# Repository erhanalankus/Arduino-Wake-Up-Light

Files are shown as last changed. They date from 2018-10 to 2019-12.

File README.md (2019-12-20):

# Arduino Wake Up Light

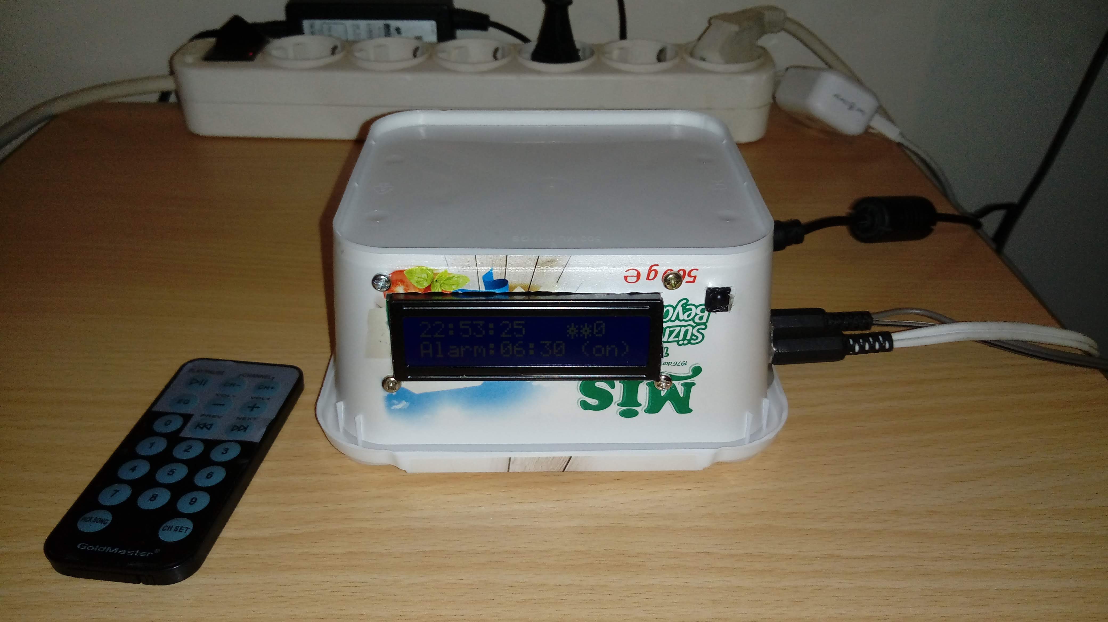
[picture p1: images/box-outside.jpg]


An alarm clock which turns on the lights very slowly. Lights can be controlled manually with an IR remote. White LED strip is for the alarm, Red LED strip is for soft light to use in the evening. It also has a buzzer, which is used to making gentle "tick" sounds when the light reaches full brightness(after 30 minutes). The tick frequency starts at one tick every two seconds, it doubles its speed after every ten minutes. The sound can be turned off.

# Step 1: Build the circuit

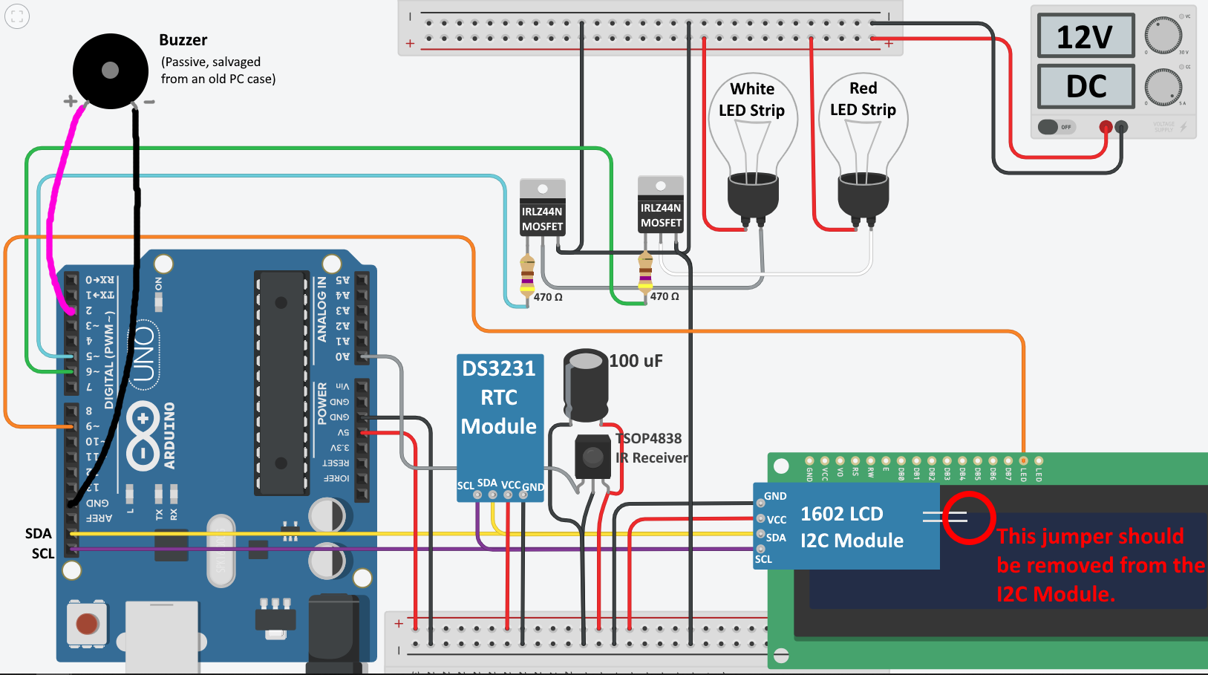
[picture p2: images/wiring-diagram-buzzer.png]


# Step 2: Set the time

Before uploading the sketch to your Arduino, change the arguments of the setDS3231time method call(in the setup method) with the current values for the time and date and uncomment the method call. Upload the sketch. Comment out the method call and upload again. The time won't be lost unless you remove the battery from the DS3231 RTC module.

# Step 3: Set the remote

Go to the "if (irrecv.decode(&results)) {...}" block. There you will find what happens for which remote button. Those values most likely won't work with the remote that you are using. Watch this video and you'll learn how to setup your remote: https://youtu.be/ftdJ0R_5NZk

This is the remote I'm using:

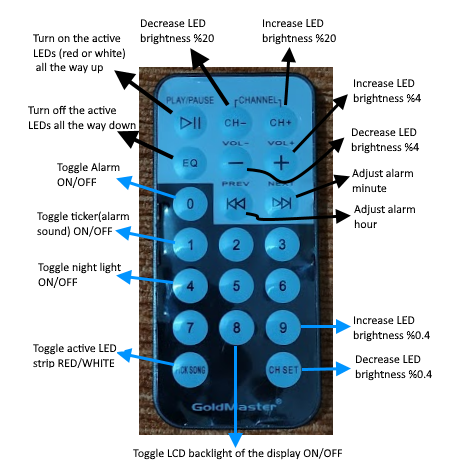
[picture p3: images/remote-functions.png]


# Step 4: Using the device

When the alarm is active, brightness of the lights will increase 1 unit every 7 seconds. Maximum brightness value is 255. Current brightness value is displayed on the top right of the LCD screen. It will take 30 minutes to reach full brightness and after the time stated in the alarmDuration variable(3 hours), the light will turn off. You can change alarm duration and speed by changing the values of alarmDuration variable and searching for the value 7000(I should have made it a variable). Pressing any button will deactivate the alarm. If "night light" function is on, a very weak red light will turn on at 01:00. If it's the "night light" function is off, all the lights will turn off at 01:00.

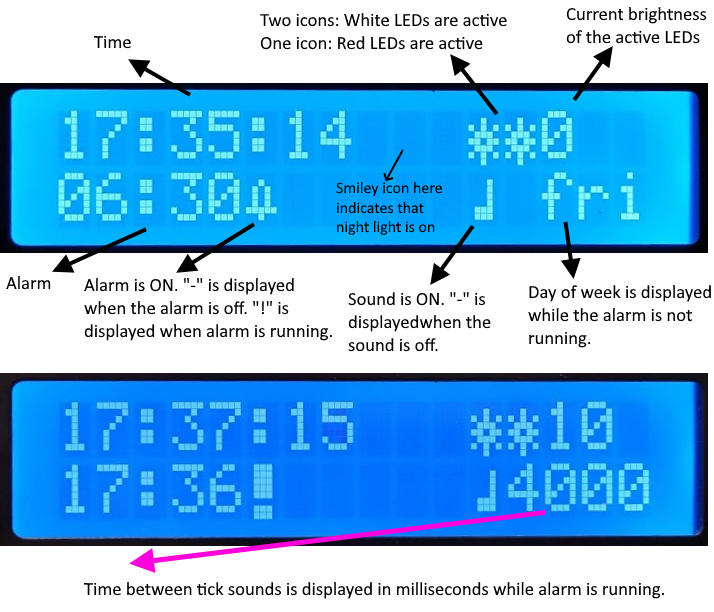
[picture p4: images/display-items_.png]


# More Pictures

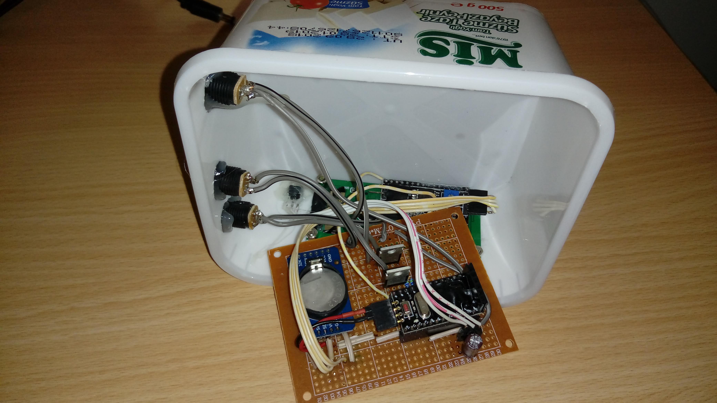
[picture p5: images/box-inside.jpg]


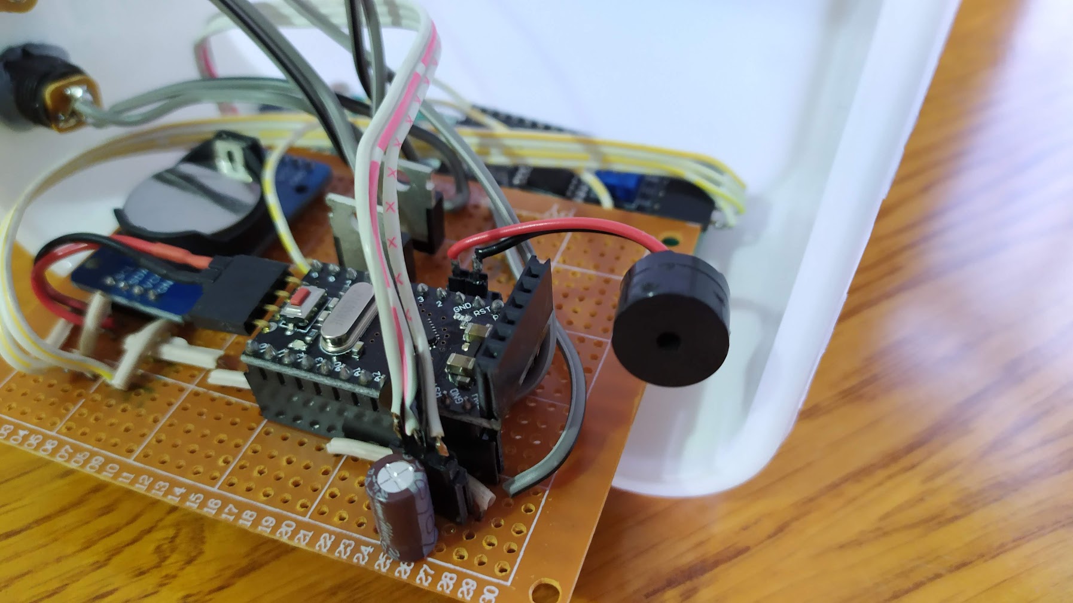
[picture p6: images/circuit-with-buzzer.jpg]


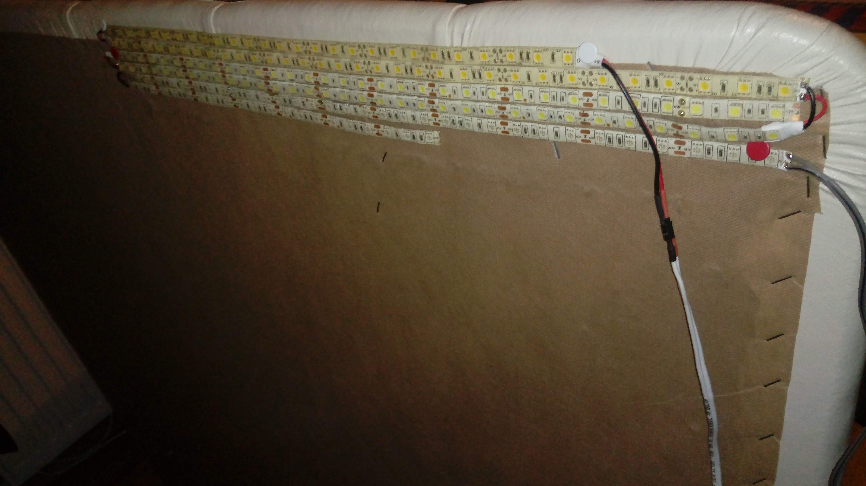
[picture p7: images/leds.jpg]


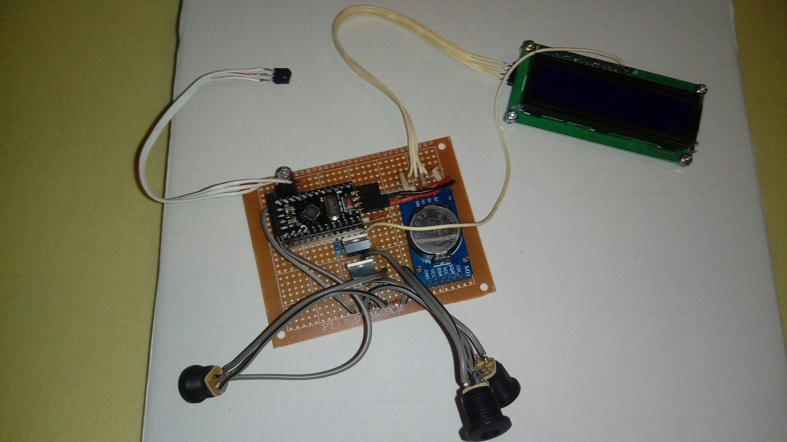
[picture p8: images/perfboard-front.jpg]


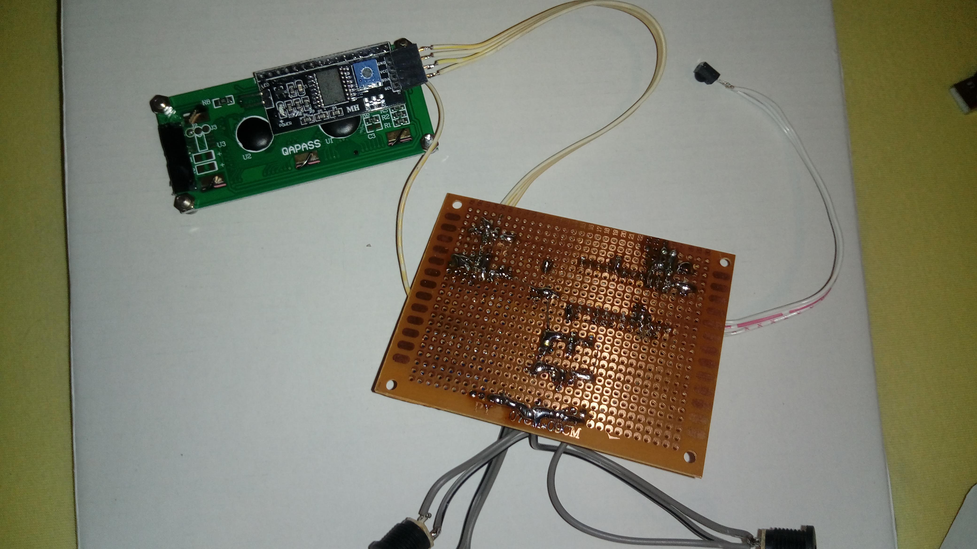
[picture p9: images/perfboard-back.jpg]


You can find the Fritzing Sketch file that I used to design the circuit on perfboard in this repository. File name is "Wake Up Light Perfboard.fzz". It is incomplete but it can be helpful.

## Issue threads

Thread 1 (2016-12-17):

Alarm time should be written on the RTC module, not Arduino

erhanalankus, 2016-12-17:
Alarm time is written on the Arduino. It will reset in case of a power loss.

erhanalankus, 2016-12-17:
Try: https://github.com/JChristensen/DS3232RTC/issues/5

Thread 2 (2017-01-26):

LCD backlight too bright

erhanalankus, 2017-01-26:

erhanalankus, 2017-01-26:
Replaced 1k resistor with 4.7k resistor. Update the schematics after testing.

erhanalankus, 2017-01-26:
Use PWM on pin9 to turn on backlight. Code in brightness values for time of day. High brightness for day, low brightness for night.

erhanalankus, 2017-01-26:
Swapped pins 9 and 2. Implemented previous comment. Should the backlight be always on at daytime?

erhanalankus, 2017-01-27:
Now backlight is always on. Brightness is determined based on time. A button on ir remote turns off backlight until the alarm is active or 9am.

Closed 2017-01-27.

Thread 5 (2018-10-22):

Backlight is too dim in the morning

erhanalankus, 2018-10-22:
When turning the alarm off, an override can be implemented to increase the LCD brightness.

erhanalankus, 2018-11-22:
The backlight should increase in sync with the alarm

erhanalankus, 2018-12-01:
Resolved with https://github.com/erhanalankus/Arduino-Wake-Up-Light/commit/64e498e410c3d79910c0a40f8fe3ba941dce5e48

Closed 2018-12-01.

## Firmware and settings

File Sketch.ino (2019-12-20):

#include <IRremote.h>			// https://github.com/z3t0/Arduino-IRremote
#include <LiquidCrystal_I2C.h>	// https://github.com/fdebrabander/Arduino-LiquidCrystal-I2C-library
#include <Wire.h>

#pragma region Definitions

// Set the LCD address to 0x3F for a 16 chars and 2 line display
// You can find the address of your I2C device using https://playground.arduino.cc/Main/I2cScanner
LiquidCrystal_I2C lcd(0x3F, 16, 2);

// 14 is A0 on Arduino UNO, this is the pin for the IR receiver
int RECV_PIN = 14;
IRrecv irrecv(RECV_PIN);
decode_results results;

const int backlightLCD = 9;
const int WhiteLEDStrip = 5;
const int RedLEDStrip = 6;
const int ticker = 2;

int activeLED = WhiteLEDStrip;

// Brightness step variables set the amount of brightness to change, while using the lights manually(not for alarm).
int brightness = 0;
int brightnessStep = 51;
int smallBrightnessStep = 10;
bool lightOn = false;

// Values to read from DS3231 RTC Module
byte second, minute, hour, dayOfWeek, dayOfMonth, month, year;

// Default alarm time, in case of power loss during the night, alarm time will reset to this.
byte alarmHour = 6;
byte alarmMinute = 30;

bool alarmOn = true;
bool alarmActive = false;
long alarmTurnedOnAt = 0;
long alarmStepTime = 0;
long lastTimeReading = 0;

// Alarm will end after 3 hours
long alarmDuration = 10800000;

long startTickingAfter = 1800000; // Thirty minutes 1800000
long startingTickerInterval = 4000;
long tickerInterval = startingTickerInterval;
long tickerStateChangeTime = 600000; // Ten minutes 600000
long tickerStateChangedAt = 0;
long tickerToggledAt = 0;
bool tickerActive = false;
bool tickerOn = false;
bool tickerEnabled = true;

int backlightBrightnessForNight = 1;
int backlightBrightnessForDay = 255;
bool isNight = false;
bool backlightManuallyTurnedOff = false;
bool nightLightEnabled = true;

// decToBcd & bcdToDec are used for reading the time from the RTC module
#define DS3231_I2C_ADDRESS 0x68
// Convert normal decimal numbers to binary coded decimal
byte decToBcd(byte val)
{
	return((val / 10 * 16) + (val % 10));
}
// Convert binary coded decimal to normal decimal numbers
byte bcdToDec(byte val)
{
	return((val / 16 * 10) + (val % 16));
}

// Brightness icon
byte sunCharacter[8] = {
	B00000,
	B00100,
	B10101,
	B01110,
	B11011,
	B01110,
	B10101,
	B00100
};

// Alarm icon
byte bellCharacter[8] = {
	B00000,
	B00100,
	B01010,
	B01010,
	B01010,
	B11111,
	B00100,
	B00000
};

// Large exclamation mark
byte exclamationCharacter[] = {
	B01110,
	B01110,
	B01110,
	B01110,
	B01110,
	B00000,
	B01110,
	B01110
};

byte soundCharacter[] = {
	B00000,
	B00010,
	B00010,
	B00010,
	B00010,
	B01110,
	B01110,
	B00000
};

byte smiley[] = {
	B00000,
	B01010,
	B01010,
	B00000,
	B10001,
	B01110,
	B00000,
	B00000
};

#pragma endregion

void setup()
{
	Wire.begin();

	lcd.begin();
	lcd.createChar(0, sunCharacter);
	lcd.createChar(1, bellCharacter);
	lcd.createChar(2, exclamationCharacter);
	lcd.createChar(3, soundCharacter);
	lcd.createChar(4, smiley);

	irrecv.enableIRIn();

	pinMode(backlightLCD, OUTPUT);
	pinMode(WhiteLEDStrip, OUTPUT);
	pinMode(RedLEDStrip, OUTPUT);
	pinMode(ticker, OUTPUT);

	analogWrite(WhiteLEDStrip, 0);
	analogWrite(RedLEDStrip, 0);

	ReadTime();
	CheckDayOrNight();

	/* set the initial time here:
	   DS3231 seconds, minutes, hours, day(1 for sunday, 2 for monday...), date, month, year
	   Set the time by uncommenting the following line after editing the values and load the sketch on your arduino. Right after that, comment out the line and load the sketch again. */
	   // setDS3231time(00,59,23,1,31,12,16);
}

void loop()
{
	if (OnceEverySecond())
	{
		ReadTime();
		lastTimeReading = millis();

		// Once every minute
		if (second == 0)
		{
			if (alarmOn)
			{
				CheckAlarm();
			}

			// Once every hour
			if (minute == 0)
			{
				CheckDayOrNight();
				if (hour == 1)
				{
					if (nightLightEnabled)
					{
						ActivateNightLight();
					}
					else
					{
						LightOff();
					}
				}
			}
		}

		SetLCDBacklight();
		RefreshLCD();
	}

	if (alarmActive)
	{
		// For the duration of alarm
		if (millis() - alarmTurnedOnAt < alarmDuration)
		{
			// Increase brightness 1 unit once in 7 seconds. The light will reach full brightness in 30 minutes.
			if (millis() - alarmStepTime > 7000)
			{
				ChangeBrightness(1);
				alarmStepTime = millis();
			}

			if (millis() - alarmTurnedOnAt > startTickingAfter)
			{
				if (millis() - tickerStateChangedAt > tickerStateChangeTime)
				{
					tickerActive = true;
					tickerStateChangedAt = millis();
					tickerToggledAt = millis();
					DecreaseTickerInterval();
				}
			}
		}
		// Once at the end of alarm duration
		else
		{
			brightness = 0;
			SetBrightness(brightness);
			alarmActive = false;
			tickerActive = false;
			tickerStateChangedAt = millis();
			tickerInterval = startingTickerInterval;
		}
	}

	if (tickerActive)
	{
		if (millis() - tickerToggledAt > tickerInterval)
		{
			tickerToggledAt = millis();
			ToggleTicker();
		}
	}

	/* IR Codes for my Remote
	Button			Code
	Play/Pause	-->	0xFFA25D
	CH-			-->	0xFF629D
	CH+			-->	0xFFE21D
	EQ			-->	0xFF22DD
	VOL-		-->	0xFF02FD
	VOL+		-->	0xFFC23D
	PREV		-->	0xFFA857
	NEXT		-->	0xFF906F
	PICK SONG	-->	0xFF42BD
	CH SET		-->	0xFF52AD
	0			-->	0xFFE01F
	1			-->	0xFF6897
	2			-->	0xFF9867
	3			-->	0xFFB04F
	4			-->	0xFF30CF
	5			-->	0xFF18E7
	6			-->	0xFF7A85
	7			-->	0xFF10EF
	8			-->	0xFF38C7
	9			-->	0xFF5AA5
	*/

	// If a button is pressed on the IR remote, see GreatScott's video for how to read the codes for your remote(https://youtu.be/ftdJ0R_5NZk)
	if (irrecv.decode(&results)) {
		if (results.value == 0xFFA25D) //PLAY button
		{
			LightOn();
			PushedAnyButton();
		}
		if (results.value == 0xFF22DD) //EQ button
		{
			LightOff();
			PushedAnyButton();
		}
		if (results.value == 0xFFE21D) //CH+ button
		{
			ChangeBrightness(brightnessStep);
			PushedAnyButton();
		}
		if (results.value == 0xFF629D) //CH- button
		{
			ChangeBrightness(-brightnessStep);
			PushedAnyButton();
		}
		if (results.value == 0xFFC23D) //VOL+ button
		{
			ChangeBrightness(smallBrightnessStep);
			PushedAnyButton();
		}
		if (results.value == 0xFF02FD) // VOL- button
		{
			ChangeBrightness(-smallBrightnessStep);
			PushedAnyButton();
		}
		if (results.value == 0xFF52AD) //CH SET button
		{
			ChangeBrightness(-1);
			PushedAnyButton();
		}
		if (results.value == 0xFF5AA5) //9 button
		{
			ChangeBrightness(1);
			PushedAnyButton();
		}
		if (results.value == 0xFFA857) //PREV button
		{
			IncreaseAlarmHour();
			PushedAnyButton();
		}
		if (results.value == 0xFF906F) //NEXT button
		{
			IncreaseAlarmMinute();
			PushedAnyButton();
		}
		if (results.value == 0xFFE01F) //0 button
		{
			ToggleAlarm();
			PushedAnyButton();
		}

		if (results.value == 0xFF42BD) //PICK SONG button
		{
			ToggleActiveLEDStrip();
			PushedAnyButton();
		}

		if (results.value == 0xFF38C7) //8 button
		{
			backlightManuallyTurnedOff = !backlightManuallyTurnedOff;
			PushedAnyButton();
		}

		if (results.value == 0xFF6897) //1 button
		{
			tickerEnabled = !tickerEnabled;
			PushedAnyButton();
		}

		if (results.value == 0xFF30CF) //4 button
		{
			nightLightEnabled = !nightLightEnabled;
			PushedAnyButton();
		}

		irrecv.resume();

		// This delay is recommended by the IRRemote library.
		delay(100);
	}
}

void ActivateNightLight() {
	LightOff();
	activeLED = RedLEDStrip;
	brightness = 10;
	SetBrightness(brightness);
}

void DecreaseTickerInterval() {
	if (tickerInterval % 2 == 1)
	{
		tickerInterval -= 1;
	}
	tickerInterval /= 2;
}

void ToggleTicker() {
	if (!tickerEnabled)
	{
		return;
	}

	if (tickerOn)
	{
		digitalWrite(ticker, LOW);
		tickerOn = false;
	}
	else
	{
		digitalWrite(ticker, HIGH);
		tickerOn = true;
	}
}

void LightOn() {
	if (brightness != 255)
	{
		brightness = 255;
		SetBrightness(brightness);
	}
	else
	{
		return;
	}
}

void LightOff() {
	if (lightOn)
	{
		brightness = 0;
		SetBrightness(brightness);
	}
	else
	{
		return;
	}
}

void SetBrightness(int brightnessValue)
{
	analogWrite(activeLED, brightnessValue);
	if (brightnessValue == 0)
	{
		lightOn = false;
	}
	else
	{
		lightOn = true;
	}
}

void PushedAnyButton()
{
	if (alarmActive)
	{
		alarmActive = false;
		LightOff();
		tickerActive = false;
		tickerStateChangedAt = millis();
		tickerInterval = startingTickerInterval;
	}
}

void ToggleActiveLEDStrip() {
	LightOff();

	if (activeLED == WhiteLEDStrip)
	{
		activeLED = RedLEDStrip;
	}
	else
	{
		activeLED = WhiteLEDStrip;
	}
}

bool OnceEverySecond() {
	if (millis() - lastTimeReading > 1000)
	{
		lastTimeReading = millis();
		return true;
	}
	else
	{
		return false;
	}
}

void ReadTime()
{
	// retrieve data from DS3231
	readDS3231time(&second, &minute, &hour, &dayOfWeek, &dayOfMonth, &month, &year);
}

void CheckAlarm()
{
	if (hour == alarmHour)
	{
		if (minute == alarmMinute)
		{
			Alarm();
		}
	}
}

void Alarm()
{
	LightOff();
	activeLED = WhiteLEDStrip;
	alarmActive = true;
	alarmTurnedOnAt = millis();
	tickerStateChangedAt = millis();
	alarmStepTime = millis();
	backlightManuallyTurnedOff = false;
}

void RefreshLCD()
{
	lcd.clear();
	PrintTimeValueOnLCD(hour);
	lcd.print(":");
	PrintTimeValueOnLCD(minute);
	lcd.print(":");
	PrintTimeValueOnLCD(second);
	lcd.print(" ");
	if (nightLightEnabled)
	{
		lcd.write(byte(4)); //smiley
	}
	else
	{
		lcd.print(" ");
	}
	if (backlightManuallyTurnedOff)
	{
		lcd.print("!");
	}
	else
	{
		lcd.print(" ");
	}
	if (activeLED == WhiteLEDStrip)
	{
		lcd.write(byte(0));
	}
	else
	{
		lcd.print(" ");
	}
	lcd.write(byte(0));
	lcd.print(brightness);

	lcd.setCursor(0, 1);
	PrintTimeValueOnLCD(alarmHour);
	lcd.print(":");
	PrintTimeValueOnLCD(alarmMinute);
	if (alarmOn)
	{
		if (alarmActive)
		{
			lcd.write(byte(2)); //Exclamation icon
		}
		else
		{
			lcd.write(byte(1)); //Bell icon
		}
	}
	else
	{
		lcd.print("-");
	}
	lcd.print("     ");
	if (tickerEnabled)
	{
		lcd.write(byte(3)); //Sound icon
	}
	else
	{
		lcd.print("-");
	}
	if (alarmActive)
	{
		lcd.print(tickerInterval);
	}
	else
	{
		lcd.print(DayOfWeekForLCD());
	}
}

String DayOfWeekForLCD() {
	switch (dayOfWeek)
	{
	case 1:
		return " sun";
		break;
	case 2:
		return " mon";
		break;
	case 3:
		return " tue";
		break;
	case 4:
		return " wed";
		break;
	case 5:
		return " thu";
		break;
	case 6:
		return " fri";
		break;
	case 7:
		return " sat";
		break;
	default:
		break;
	}
}

void PrintTimeValueOnLCD(byte value)
{
	if (value < 10)
	{
		lcd.print(0);
	}
	lcd.print(value);
}

void ChangeBrightness(int step) {
	brightness += step;
	if (brightness > 255)
	{
		brightness = 255;
	}
	if (brightness < 0)
	{
		brightness = 0;
	}
	SetBrightness(brightness);
}

void IncreaseAlarmHour()
{
	if (alarmHour == 23)
	{
		alarmHour = 0;
	}
	else
	{
		alarmHour++;
	}
	RefreshLCD();
}

void IncreaseAlarmMinute()
{
	if (alarmMinute == 59)
	{
		alarmMinute = 0;
	}
	else
	{
		alarmMinute++;
	}
	RefreshLCD();
}

void ToggleAlarm()
{
	alarmOn = !alarmOn;
	RefreshLCD();
}

void CheckDayOrNight() {
	if ((hour >= 21) || (hour >= 0 && hour < 9))
	{
		isNight = true;
	}
	else
	{
		isNight = false;
	}
}

void SetLCDBacklight() {
	if (backlightManuallyTurnedOff)
	{
		analogWrite(backlightLCD, 0);
	}
	else if (alarmActive)
	{
		analogWrite(backlightLCD, brightness);
	}
	else
	{
		if (isNight)
		{
			analogWrite(backlightLCD, backlightBrightnessForNight);
		}
		else
		{
			analogWrite(backlightLCD, backlightBrightnessForDay);
		}
	}
}

void setDS3231time(byte second, byte minute, byte hour, byte dayOfWeek,
	byte dayOfMonth, byte month, byte year)
{
	// sets time and date data to DS3231
	Wire.beginTransmission(DS3231_I2C_ADDRESS);
	Wire.write(0); // set next input to start at the seconds register
	Wire.write(decToBcd(second)); // set seconds
	Wire.write(decToBcd(minute)); // set minutes
	Wire.write(decToBcd(hour)); // set hours
	Wire.write(decToBcd(dayOfWeek)); // set day of week (1=Sunday, 7=Saturday)
	Wire.write(decToBcd(dayOfMonth)); // set date (1 to 31)
	Wire.write(decToBcd(month)); // set month
	Wire.write(decToBcd(year)); // set year (0 to 99)
	Wire.endTransmission();
}
void readDS3231time(byte* second, byte* minute, byte* hour, byte* dayOfWeek,
	byte* dayOfMonth, byte* month, byte* year)
{
	Wire.beginTransmission(DS3231_I2C_ADDRESS);
	Wire.write(0); // set DS3231 register pointer to 00h
	Wire.endTransmission();
	Wire.requestFrom(DS3231_I2C_ADDRESS, 7);
	// request seven bytes of data from DS3231 starting from register 00h
	*second = bcdToDec(Wire.read() & 0x7f);
	*minute = bcdToDec(Wire.read());
	*hour = bcdToDec(Wire.read() & 0x3f);
	*dayOfWeek = bcdToDec(Wire.read());
	*dayOfMonth = bcdToDec(Wire.read());
	*month = bcdToDec(Wire.read());
	*year = bcdToDec(Wire.read());
}

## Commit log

2017-04-08 Sleep mode added
    At 02:00, device will turn off the lights and backlight, switch to 12V leds.
2018-10-15 Add Wiring Diagram Image
2018-10-20 Fix Faulty Sun Character & Refactoring
    [Sketch.ino]
2018-10-20 Fix LCD Backlight Bug
    [Sketch.ino]
2018-10-21 Add Fritzing Sketch
    [Wake Up Light Perfboard.fzz]
2018-12-01 Fix Bugs
    Turn the lights off at 1 AM.
    When the alarm is active, the LCD backlight will increase with the alarm lights.
    [Sketch.ino]
